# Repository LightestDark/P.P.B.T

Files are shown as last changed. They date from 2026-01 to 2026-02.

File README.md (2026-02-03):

# P.P.B.T

This project is a low-power smart keychain that combines E-paper display technology with NFC, designed to work with minimal energy and remain readable even when completely unpowered.

The system is split into two separate modules:

-E-Paper + NFC Keychain Board

Waveshare e paper display is used, following the websites recommended parts, using a crystal oscillator for graphics and a tiny flash memory for the images!
Used an NFC tag plugin for the coil for the NFC tag which calculates the impedance of the coil!

Added extra male pins for future endeavours if i want to add things to the board?

-Solar-Powered DC-DC Booster Board (external, detachable)

Follows a old schematic for an IKEA outdoor light, repurposed with smaller parts to make it cheaper, it uses a buckboost converter to get a steady flow from the solar panel to safely charge or power anything, in my case a strip of leds i will stick on the board case!

**This separation keeps the keychain compact, efficient, and flexible.**

**E PAPER + NFC SCHEMATIC/BOARD/MODEL:**







** SOLAR POWERED PSU **







The e-paper display shows text or graphics and keeps the image with zero power. Power is only needed when the display updates.
The NFC works passively, powered by the reader, allowing phones to scan the keychain even if the battery is empty.

To keep the main board simple and efficient, LED lighting is powered by a separate solar-powered DC-DC booster board. This board takes energy from a small solar panel and boosts it to drive LEDs around the keychain, without affecting the e-paper or NFC system.

CASE:

Pretty happy with the colour scheme and how it looks!





Main points of note:
PLA (probably)
Added tolerances for easy fitting since im hoping to use a friciton for the lid and the bottom
Added heat set insert holes
Added male header pin space for added functionality in the future
Added solar powered pcb on the underside, that will be wired to external solar panel and a led strip stuck onto the board
Added keychain hole onto the board (for coolness)

Underside:


Solar powered pcb on underside:



Under the hood:




Hopefully this is good enough to protect the board!

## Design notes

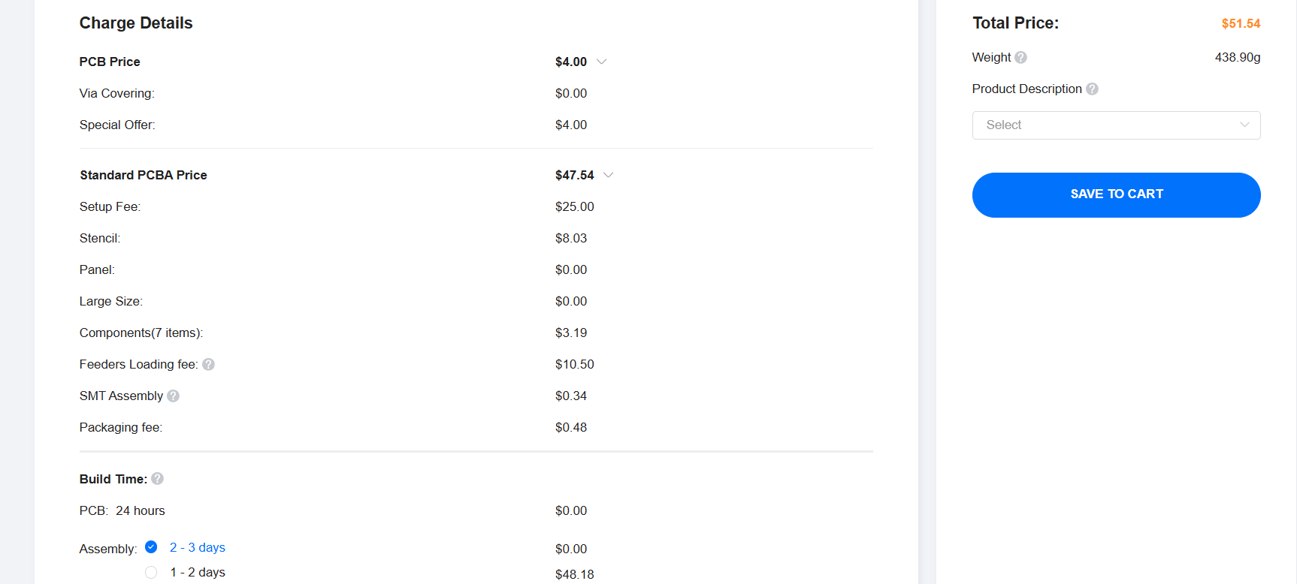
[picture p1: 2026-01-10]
Pictures/Jclpcb pt 2.png

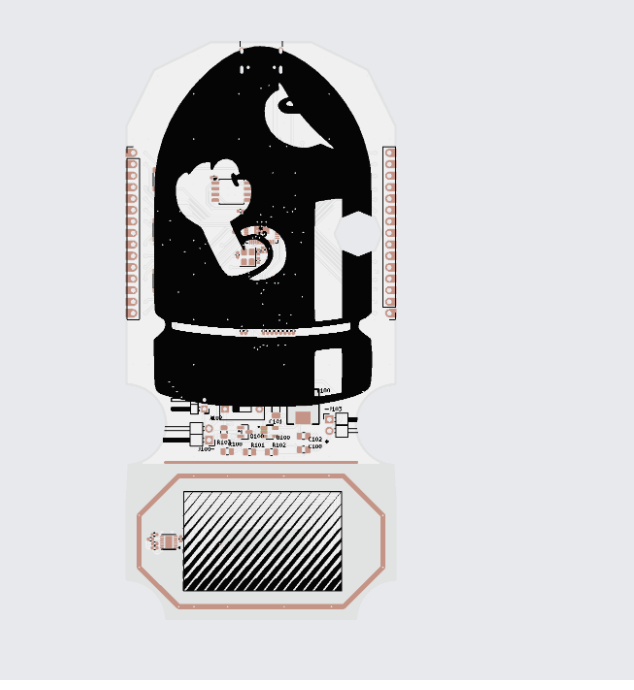
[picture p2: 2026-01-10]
Pictures/Screenshot 2026-01-10 211034.png

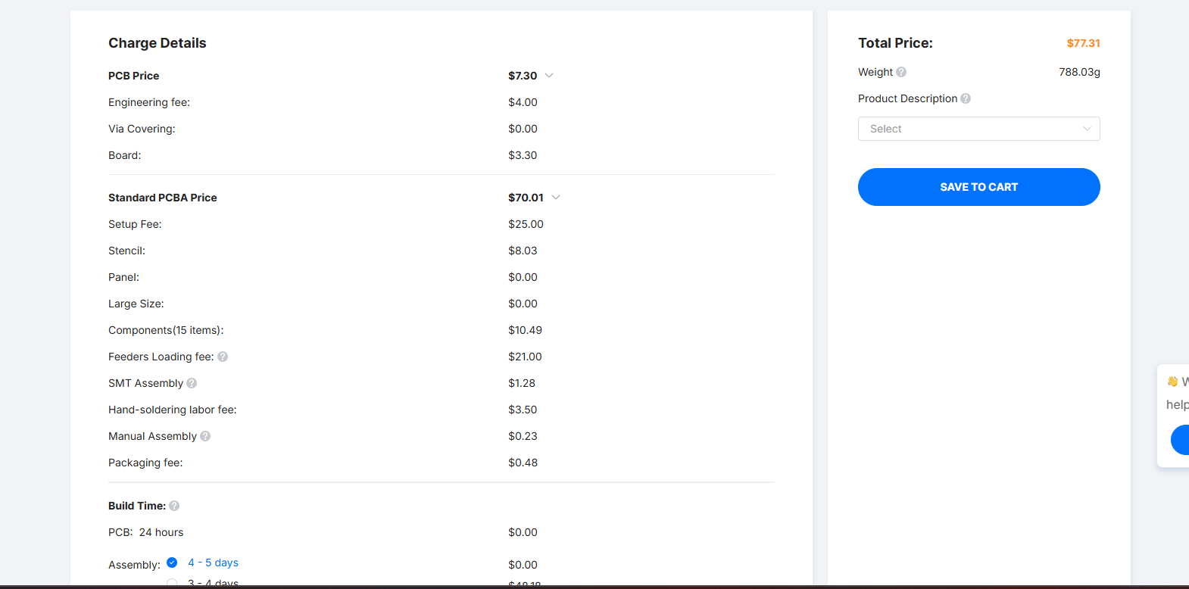
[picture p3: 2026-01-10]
Pictures/JCLPCB1.png

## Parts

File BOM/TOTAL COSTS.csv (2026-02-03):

Item No | Category | Item Name | Source | Unit Cost (USD) | Notes
1 | JLCPCB Assembly | E-Paper + NFC Board | JLCPCB | 94.58 | Full PCB fabrication + assembly
2 | JLCPCB Assembly | Solar Panel PSU Board | JLCPCB | 29.89 | Boost converter PCB fabrication + assembly
3 | External (Not JLCPCB) | 2.9 inch E-Paper Display | Waveshare | 15.00 | https://www.waveshare.com/2.9inch-e-paper-module-g.htm?sku=33215
4 | External (Not JLCPCB) | Solar Panel Module | Amazon | 5.00 | https://www.amazon.co.uk/dp/B0BKLP2B96
5 | Total | GRAND TOTAL (INC SHIPPING) |  | 154.85 | Sum of all costs

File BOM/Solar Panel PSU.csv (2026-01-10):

Comment | Designator | Footprint | LCSC / Source Part # | Manufacturer / MPN | Quantity | Unit Price (USD) | Total (USD)
DC-DC Boost Converter | U1 | SOT-23-5 | C20582 | AP3015AKTR-G1 | 1 | 0.23 | 0.23
Inductor 10uH | L1 | 0603 | C19702 | LQM15AN103B0D | 1 | 0.12 | 0.12
Schottky Diode | D1 | SMA | C8678 | SS14 | 1 | 0.06 | 0.06
Schottky Diode | D2 | SMA | C8678 | SS14 | 1 | 0.06 | 0.06
N-Channel MOSFET | Q1 | SOT-23 | C8545 | 2N7002 | 1 | 0.05 | 0.05
Resistor 1M | R1 | 0603 | C22936 | 0603WAF1004T5E | 1 | 0.001 | 0.001
Resistor 604k | R2 | 0603 | C25809 | 0603WAF6043T5E | 1 | 0.002 | 0.002
Resistor 100k | R3 | 0603 | C25803 | 0603WAF1003T5E | 1 | 0.001 | 0.001
Resistor 10Ω | R4 | 0603 | C22859 | 0603WAF100JT5E | 1 | 0.001 | 0.001
Capacitor 4.7uF 50V | C1 | 0805 | C29823 | CL21B475KBFNNNE | 1 | 0.03 | 0.03
Capacitor 22uF 10V | C2 | 1206 | C13585 | CL31A226KPHNNNE | 1 | 0.08 | 0.08
Capacitor 10uF 50V | C3 | 0805 | C15850 | CL21B106KPQNNNE | 1 | 0.05 | 0.05
2-Pin Header | J1 | Through-hole | C124378 | PinHeader 2P 2.54mm | 1 | 0.05 | 0.05
2-Pin Header | J2 | Through-hole | C124378 | PinHeader 2P 2.54mm | 1 | 0.05 | 0.05
2-Pin Header | J4 | Through-hole | C124378 | PinHeader 2P 2.54mm | 1 | 0.05 | 0.05
Slide Switch | SW1 | Through-hole | C318884 | Mini Slide Switch | 1 | 0.25 | 0.25
Solar Panel | SP1 | Wire leads | Elektor 11931 | Elektor 11931 | 1 | 6.50 | 6.50

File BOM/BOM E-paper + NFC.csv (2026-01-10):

JLCPCB BOM Tool - BOM Matching
BOM name：bom-JLCPCB Assembly Order.xlsx |  |  | Download Time：2026-01-05 06:33:50 |  |  |  | * Our matching results are updated in real-time, but stock and prices may change. If it's been over 24 hours, please re-match before placing your order.
PCB Assembled Qty：5 |  |  | Est. Total Price：15.1631
Your BOM |  |  |  |  | Matched Parts |  |  |  |  |  |  | Order Information
Top Designator | Bottom Designator | Comment | Footprint | JLCPCB Part # | Matches | Part # | Manufacturer | Footprint | Description | Category | Warning | JLCPCB Part # | Product link | Lib Type | Qty | Source | Total Price ($)
C1,C2 |  | 10uF | 0805 |  | Select by System | CL21A106KAYNNNE | Samsung Electro-Mechanics | 0805 | 10uF 25V X5R ±10% 0805 Multilayer Ceramic Capacitors MLCC - SMD/SMT ROHS | Multilayer Ceramic Capacitors MLCC - SMD/SMT |  | C15850 | https://jlcpcb.com/partdetail/16532-CL21A106KAYNNNE/C15850 | Basic | 10 | 10 JLCPCB | 0.098
C10,C12,C13,C16,C29,C4,C5,C6,C7,C8,C9 |  | 0.1uF | 0402 |  | Unconfirmed | CL05B104KO5NNNC | Samsung Electro-Mechanics | 0402 | 100nF 16V X7R ±10% 0402 Multilayer Ceramic Capacitors MLCC - SMD/SMT ROHS | Multilayer Ceramic Capacitors MLCC - SMD/SMT | 1.The comment (CL05B104KO5NNNC) of this part does not match the one (0.1uF) provided in your BOM. Please confirm; | C1525 | https://jlcpcb.com/partdetail/1877-CL05B104KO5NNNC/C1525 | Basic | 55 | 55 JLCPCB | 0.066
C11,C17,C18,C19,C20,C21,C22,C23,C24,C25,C26,C3 |  | 1uF | 0402 |  | Select by System | CL05A105KA5NQNC | Samsung Electro-Mechanics | 0402 | 1uF 25V X5R ±10% 0402 Multilayer Ceramic Capacitors MLCC - SMD/SMT ROHS | Multilayer Ceramic Capacitors MLCC - SMD/SMT |  | C52923 | https://jlcpcb.com/partdetail/53938-CL05A105KA5NQNC/C52923 | Basic | 60 | 60 JLCPCB | 0.174
C14,C15,C30 |  | 33pF | 0402 |  | Select by System | 0402CG330J500NT | FH (Guangdong Fenghua Advanced Tech) | 0402 | 33pF 50V C0G ±5% 0402 Multilayer Ceramic Capacitors MLCC - SMD/SMT ROHS | Multilayer Ceramic Capacitors MLCC - SMD/SMT |  | C1562 | https://jlcpcb.com/partdetail/1914-0402CG330J500NT/C1562 | Basic | 15 | 15 JLCPCB | 0.015
C27,C28 |  | 4.7uF | 0603 |  | Select by System | CL10A475KO8NNNC | Samsung Electro-Mechanics | 0603 | 16V 4.7uF X5R ±10% 0603 Multilayer Ceramic Capacitors MLCC - SMD/SMT ROHS | Multilayer Ceramic Capacitors MLCC - SMD/SMT |  | C19666 | https://jlcpcb.com/partdetail/20375-CL10A475KO8NNNC/C19666 | Basic | 10 | 10 JLCPCB | 0.092
D1 |  | KT-0805G | 0805 |  | Select by System | KT-0805G | Hubei KENTO Elec | 0805 | -40℃~+85℃ 100mW 120° 2.6V~3.1V 430mcd 513nm~528nm 525nm 5mA Emerald Green 0805 LED Indication - Discrete ROHS | LED Indication - Discrete |  | C2297 | https://jlcpcb.com/partdetail/Hubei_KENTOElec-KT0805G/C2297 | Basic | 5 | 5 JLCPCB | 0.054
D2,D3,D4 |  | MBR0530 | D_SOD-123 |  | Select by System | MBR0530 | TWGMC | SOD-123 | 130uA 30V 5.5A 500mA 500mV@500mA Independent SOD-123 Schottky Diodes ROHS | Schottky Diodes |  | C5204746 | https://jlcpcb.com/partdetail/TWGMC-MBR0530/C5204746 | Extended | 23 | 23 JLCPCB | 0.4278
J1 |  | USB_C_Receptacle_USB2.0_16P | USB_C_Receptacle_HRO_TYPE-C-31-M-12 |  | Select by Customer | TYPE-C-31-M-12 | Korean Hroparts Elec | SMD | 1 16P 5A Female Type-C SMD USB Connectors ROHS | USB Connectors |  | C165948 | https://jlcpcb.com/partdetail/Korean_HropartsElec-TYPE_C_31_M12/C165948 | Extended | 5 | 5 JLCPCB | 0.847
L2 |  | 68uH | L_Changjiang_FNR6028S |  | Select by Customer | FNR6028S680MT | cjiang (Changjiang Microelectronics Tech) | SMD,6x6mm | 468mΩ 68uH 950mA 950mA Magnetic Shielded Inductor ±20% SMD,6x6mm Power Inductors ROHS | Power Inductors |  | C168045 | https://jlcpcb.com/partdetail/179428-FNR6028S680MT/C168045 | Extended | 6 | 6 JLCPCB | 0.3978
Q2 |  | IRLML2060 | SOT-23 |  | Unconfirmed | IRLML2060TRPBF | TECH PUBLIC | SOT-23 | 105mΩ@10V 19.5pF 247pF 2V 34pF 350mW 3A 60V 6nC@4.5V SOT-23 MOSFETs ROHS | MOSFETs | 1.The comment (IRLML2060TRPBF) of this part does not match the one (IRLML2060) provided in your BOM. Please confirm; | C5122027 | https://jlcpcb.com/partdetail/TECHPUBLIC-IRLML2060TRPBF/C5122027 | Extended | 9 | 9 JLCPCB | 0.5607
R1,R2 |  | 5.1K | 0402 |  | Unconfirmed | 0402WGF5101TCE | UNI-ROYAL(Uniroyal Elec) | 0402 | -55℃~+155℃ 5.1kΩ 50V 62.5mW Thick Film Resistor ±1% ±100ppm/℃ 0402 Chip Resistor - Surface Mount ROHS | Chip Resistor - Surface Mount | 1.The comment (0402WGF5101TCE) of this part does not match the one (5.1K) provided in your BOM. Please confirm; | C25905 | https://jlcpcb.com/partdetail/26648-0402WGF5101TCE/C25905 | Basic | 10 | 10 JLCPCB | 0.005
R3,R4 |  | 22 | 0402 |  | Unconfirmed | 0402WGF220JTCE | UNI-ROYAL(Uniroyal Elec) | 0402 | -55℃~+155℃ 22Ω 50V 62.5mW Thick Film Resistor ±1% ±100ppm/℃ 0402 Chip Resistor - Surface Mount ROHS | Chip Resistor - Surface Mount | 1.The comment (0402WGF220JTCE) of this part does not match the one (22) provided in your BOM. Please confirm; | C25092 | https://jlcpcb.com/partdetail/25835-0402WGF220JTCE/C25092 | Basic | 10 | 10 JLCPCB | 0.006
R6,R9 |  | 1K | 0402 |  | Unconfirmed | 0402WGF1001TCE | UNI-ROYAL(Uniroyal Elec) | 0402 | -55℃~+155℃ 1kΩ 50V 62.5mW Thick Film Resistor ±1% ±100ppm/℃ 0402 Chip Resistor - Surface Mount ROHS | Chip Resistor - Surface Mount | 1.The comment (0402WGF1001TCE) of this part does not match the one (1K) provided in your BOM. Please confirm; | C11702 | https://jlcpcb.com/partdetail/12256-0402WGF1001TCE/C11702 | Basic | 10 | 10 JLCPCB | 0.006
R7 |  | 220 | 0402 |  | Unconfirmed | 0402WGF2200TCE | UNI-ROYAL(Uniroyal Elec) | 0402 | -55℃~+155℃ 220Ω 50V 62.5mW Thick Film Resistor ±1% ±100ppm/℃ 0402 Chip Resistor - Surface Mount ROHS | Chip Resistor - Surface Mount | 1.The comment (0402WGF2200TCE) of this part does not match the one (220) provided in your BOM. Please confirm; | C25091 | https://jlcpcb.com/partdetail/25834-0402WGF2200TCE/C25091 | Basic | 5 | 5 JLCPCB | 0.003
R10,R11,R13,R14,R5,R8 |  | 10K | 0402 |  | Unconfirmed | 0402WGF1002TCE | UNI-ROYAL(Uniroyal Elec) | 0402 | -55℃~+155℃ 10kΩ 50V 62.5mW Thick Film Resistor ±1% ±100ppm/℃ 0402 Chip Resistor - Surface Mount ROHS | Chip Resistor - Surface Mount | 1.The comment (0402WGF1002TCE) of this part does not match the one (10K) provided in your BOM. Please confirm; | C25744 | https://jlcpcb.com/partdetail/26487-0402WGF1002TCE/C25744 | Basic | 30 | 30 JLCPCB | 0.015
R12 |  | 0.47 | 0402 |  | Unconfirmed | 0402WGF470LTCE | UNI-ROYAL(Uniroyal Elec) | 0402 | -55℃~+155℃ 470mΩ 50V 62.5mW Thick Film Resistor ±1% ±800ppm/℃ 0402 Chip Resistor - Surface Mount ROHS | Chip Resistor - Surface Mount | 1.The comment (0402WGF470LTCE) of this part does not match the one (0.47) provided in your BOM. Please confirm; | C423162 | https://jlcpcb.com/partdetail/416112-0402WGF470LTCE/C423162 | Extended | 20 | 20 JLCPCB | 0.078
SW1,SW2,SW3 |  | TSA016A2526B | SW_Push_SPST_TSA016 |  | Select by System | TSA016A2526B | BZCN | SMD,4.2x3.4mm | 12V 2.5mm 2.6N 3.35mm 4.2mm 50mA Oval Button Surface Mount,Vertical White SMD,4.2x3.4mm Tactile Switches ROHS | Tactile Switches |  | C2888429 | https://jlcpcb.com/partdetail/BZCN-TSA016A2526B/C2888429 | Extended | 20 | 20 JLCPCB | 0.418
U1 |  | RP2040 | QFN-56-1EP_7x7mm_P0.4mm_EP3.2x3.2mm |  | Select by Customer | RP2040 | Raspberry Pi | LQFN-56(7x7) | 12bit 133MHz 30 LQFN-56(7x7) Microcontrollers (MCU/MPU/SOC) ROHS | Microcontrollers (MCU/MPU/SOC) |  | C2040 | https://jlcpcb.com/partdetail/RaspberryPi-RP2040/C2040 | Extended | 5 | 5 JLCPCB | 4.5825
U2 |  | USBLC6-2SC6 | SOT-23-6 |  | Select by System | USBLC6-2SC6 | TECH PUBLIC | SOT-23-6 | -55℃~+125℃ 0.35pF 12V 150W 2 5V 6A 6V 80nA ESD IEC 61000-4-2 Unidirectional SOT-23-6 ESD and Surge Protection (TVS/ESD) ROHS | ESD And Surge Protection (TVS/ESD) |  | C2827654 | https://jlcpcb.com/partdetail/TECHPUBLIC-USBLC62SC6/C2827654 | Extended | 9 | 9 JLCPCB | 0.3348
U3 |  | NCP1117ST33T3G | SOT-223-3_TabPin2 |  | Select by System | NCP1117ST33T3G | onsemi | SOT-223 | 0.003%Vout 0℃~+125℃@(Ta) 1 1.2V@(800mA) 1A 20V 3.3V 62dB@(120Hz) 6mA Fixed Over Current Protection Positive SOT-223 Voltage Regulators - Linear, Low Drop Out (LDO) Regulators ROHS | Voltage Regulators - Linear, Low Drop Out (LDO) Regulators |  | C26537 | https://jlcpcb.com/partdetail/onsemi-NCP1117ST33T3G/C26537 | Extended | 5 | 5 JLCPCB | 1.119
U4 |  | W25Q32JVSS | SOIC-8_5.3x5.3mm_P1.27mm |  | Unconfirmed | W25Q32JVSSIQ | Winbond Elec | SOIC-8-208mil | -40℃~+85℃ 100,000 Cycles 133MHz 1uA 2.7V~3.6V 20 Years 32Mbit 3ms SPI SOIC-8-208mil NOR FLASH ROHS | NOR FLASH | 1.The comment (W25Q32JVSSIQ) of this part does not match the one (W25Q32JVSS) provided in your BOM. Please confirm; | C179173 | https://jlcpcb.com/partdetail/WinbondElec-W25Q32JVSSIQ/C179173 | Extended | 5 | 5 JLCPCB | 3.2475
U5 |  | Conn | LCSC_1x24-1MP_P0.5mm_Horizontal |  | Select by System | AFC07-S24FCA-00 | JUSHUO | SMD,P=0.5mm,卧贴 | 0.3mm 0.5mm 24P 2mm Bottom Contact Copper Alloy Slide Lock Surface Mount, Right Angle Tin SMD,P=0.5mm,Surface Mount，Right Angle FFC, FPC (Flat Flexible) Connector Assemblies ROHS | FFC, FPC (Flat Flexible) Connector Assemblies |  | C262567 | https://jlcpcb.com/partdetail/JUSHUO-AFC07_S24FCA00/C262567 | Extended | 5 | 5 JLCPCB | 0.5985
U6 |  | ST25DV04K-JFR6D3 | ST_UFDFPN-12-1EP_3x3mm_P0.5mm_EP1.4x2.55mm |  | Select by System | ST25DV04K-JFR6D3 | STMicroelectronics | UDFN-12-EP(3x3) | 1.8V~5.5V 53Kbit/s I2C ISO 15693,NFC UDFN-12-EP(3x3) RFID ICs ROHS | RFID ICs |  | C2654815 | https://jlcpcb.com/partdetail/STMicroelectronics-ST25DV04KJFR6D3/C2654815 | Extended | 5 | 5 JLCPCB | 1.695
Y1 |  | 12MHz | Crystal_SMD_3225-4Pin_3.2x2.5mm |  | Select by Customer | X322512MSB4SI | YXC Crystal Oscillators | SMD3225-4P | -40℃~+85℃ 12MHz 20pF Crystal Oscillator ±10ppm ±20ppm SMD3225-4P Crystals ROHS | Crystals |  | C9002 | https://jlcpcb.com/partdetail/YXC_CrystalOscillators-X322512MSB4SI/C9002 | Basic | 5 | 5 JLCPCB | 0.3225
J2,J3 |  | Conn_01x15 | PinHeader_PAD_1x15_P2.54mm_Vertical |  | No matches | No Part Selected
L1 |  | NFCAntenna | 25x35mm-NFC |  | No matches | No Part Selected

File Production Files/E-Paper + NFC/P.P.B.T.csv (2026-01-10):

Reference | Qty | Value | DNP | Exclude from BOM | Exclude from Board | Footprint | Datasheet
C1,C2 | 2 | 10uF |  |  |  | Capacitor_SMD:C_0805_2012Metric | ~
C3,C11,C17,C18,C19,C20,C21,C22,C23,C24,C25,C26 | 12 | 1uF |  |  |  | Capacitor_SMD:C_0402_1005Metric | ~
C4,C5,C6,C7,C8,C9,C10,C12,C13,C16,C29 | 11 | 0.1uF |  |  |  | Capacitor_SMD:C_0402_1005Metric | ~
C14,C15,C30 | 3 | 33pF |  |  |  | Capacitor_SMD:C_0402_1005Metric | ~
C27,C28 | 2 | 4.7uF |  |  |  | Capacitor_SMD:C_0603_1608Metric | ~
C101 | 1 | 4.7 μF 50 V X7R |  |  |  | Capacitor_SMD:C_0805_2012Metric | ~
C102 | 1 | 10 pF 50 V X7R |  |  |  | Capacitor_SMD:C_0805_2012Metric | ~
C103 | 1 | 22 μF 10 V X7R |  |  |  | Capacitor_SMD:C_1206_3216Metric | ~
D1 | 1 | KT-0805G |  |  |  | LED_SMD:LED_0805_2012Metric | ~
D2,D3,D4 | 3 | MBR0530 |  |  |  | Diode_SMD:D_SOD-123 | http://www.mccsemi.com/up_pdf/MBR0520~MBR0580(SOD123).pdf
D101,D102 | 2 | SS14 |  |  |  | SS14:DIOM4325X250N
J1 | 1 | USB_C_Receptacle_USB2.0_16P |  |  |  | Connector_USB:USB_C_Receptacle_HRO_TYPE-C-31-M-12 | https://www.usb.org/sites/default/files/documents/usb_type-c.zip
J2,J3 | 2 | Conn_01x15 |  |  |  | kai's library:PinHeader_PAD_1x15_P2.54mm_Vertical | ~
J101 | 1 | Conn_01x02_Pin |  |  |  | Connector_PinHeader_2.00mm:PinHeader_1x02_P2.00mm_Horizontal | ~
J102,J103,J104 | 3 | Conn_01x02_Pin |  |  |  | Connector_PinHeader_2.54mm:PinHeader_1x02_P2.54mm_Vertical | ~
L1 | 1 | NFC Antenna |  |  |  | nfc:25x35mm-NFC | ~
L2 | 1 | 68uH |  |  |  | Inductor_SMD:L_Changjiang_FNR6028S | ~
L101 | 1 | ASPI-0630LR-100M-T15 |  |  |  | footprints_coil:IND_ASPI-0630LR_ABR | ASPI-0630LR-100M-T15
Q2 | 1 | IRLML2060 |  |  |  | Package_TO_SOT_SMD:SOT-23 | https://www.infineon.com/dgdl/irlml2060pbf.pdf?fileId=5546d462533600a401535664b7fb25ee
Q101 | 1 | 2N7002 |  |  |  | Package_TO_SOT_SMD:SOT-23 | https://www.onsemi.com/pub/Collateral/NDS7002A-D.PDF
R1,R2 | 2 | 5.1K |  |  |  | Resistor_SMD:R_0402_1005Metric | ~
R3,R4 | 2 | 22 |  |  |  | Resistor_SMD:R_0402_1005Metric | ~
R5,R8,R10,R11,R13,R14 | 6 | 10K |  |  |  | Resistor_SMD:R_0402_1005Metric | ~
R6,R9 | 2 | 1K |  |  |  | Resistor_SMD:R_0402_1005Metric | ~
R7 | 1 | 220 |  |  |  | Resistor_SMD:R_0402_1005Metric | ~
R12 | 1 | 0.47 |  |  |  | Resistor_SMD:R_0402_1005Metric | ~
R101,R103 | 2 | 1 ΜΩ |  |  |  | Resistor_SMD:R_0805_2012Metric | ~
R102 | 1 | 10 kΩ |  |  |  | Resistor_SMD:R_0805_2012Metric | ~
R104 | 1 | 604 kΩ 1% |  |  |  | Resistor_SMD:R_0805_2012Metric | ~
SW1,SW2,SW3 | 3 | TSA016A2526B |  |  |  | kai's library:SW_Push_SPST_TSA016 | ~
U1 | 1 | RP2040 |  |  |  | Package_DFN_QFN:QFN-56-1EP_7x7mm_P0.4mm_EP3.2x3.2mm | https://datasheets.raspberrypi.com/rp2040/rp2040-datasheet.pdf
U2 | 1 | USBLC6-2SC6 |  |  |  | Package_TO_SOT_SMD:SOT-23-6 | https://www.st.com/resource/en/datasheet/usblc6-2.pdf
U3 | 1 | NCP1117ST33T3G |  |  |  | Package_TO_SOT_SMD:SOT-223-3_TabPin2 | http://www.onsemi.com/pub_link/Collateral/NCP1117-D.PDF
U4 | 1 | W25Q32JVSS |  |  |  | Package_SO:SOIC-8_5.3x5.3mm_P1.27mm | http://www.winbond.com/resource-files/w25q32jv%20revg%2003272018%20plus.pdf
U5 | 1 | Conn |  |  |  | kai's library:LCSC_1x24-1MP_P0.5mm_Horizontal
U6 | 1 | ST25DV04K-JFR6D3 |  |  |  | Package_DFN_QFN:ST_UFDFPN-12-1EP_3x3mm_P0.5mm_EP1.4x2.55mm | https://www.st.com/resource/en/datasheet/st25dv04k.pdf
U101 | 1 | AP3015AKTR-G1 |  |  |  | AP3015AKTR-G1:SOT95P280X145-5N
Y1 | 1 | 12MHz |  |  |  | Crystal:Crystal_SMD_3225-4Pin_3.2x2.5mm | ~

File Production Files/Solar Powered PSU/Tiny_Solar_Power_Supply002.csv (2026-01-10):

Reference | Qty | Value | DNP | Exclude from BOM | Exclude from Board | Footprint | Short Description
C1 | 1 | 4.7uF, 50V, X7R (0805) |  |  |  | Capacitor_SMD:C_0805_2012Metric
C2 | 1 | 22uF, 10V, X7R (1206) |  |  |  | Capacitor_SMD:C_1206_3216Metric
C3 | 1 | 10pF, 50V, X7R (0805) |  |  |  | Capacitor_SMD:C_0805_2012Metric
D1,D2 | 2 | SS14 |  |  |  | Diode_SMD:D_SMA
J1,J2,J3 | 3 | Conn_01x02_Pin |  |  |  | Connector_PinHeader_2.54mm:PinHeader_1x02_P2.54mm_Vertical | BAT,ON/OFF,OUT
J4 | 1 | Conn_01x02_Pin |  |  |  | Connector_PinHeader_2.54mm:PinHeader_1x02_P2.54mm_Horizontal | SOLAR
L1 | 1 | LQW15AN1N3C80D |  |  |  | IND_LQW15_MUR
Q1 | 1 | 2N7002 |  |  |  | digikey-footprints:SOT-23-3
R1,R4 | 2 | 1MOhm |  |  |  | Resistor_SMD:R_0805_2012Metric
R2 | 1 | 604 kOhm |  |  |  | Resistor_SMD:R_0805_2012Metric
R3 | 1 | 10kOhm |  |  |  | Resistor_SMD:R_0805_2012Metric
U1 | 1 | AP3015AKTR-G1 |  |  |  | footprints:SOT23-5_1P55X2P9_DIO

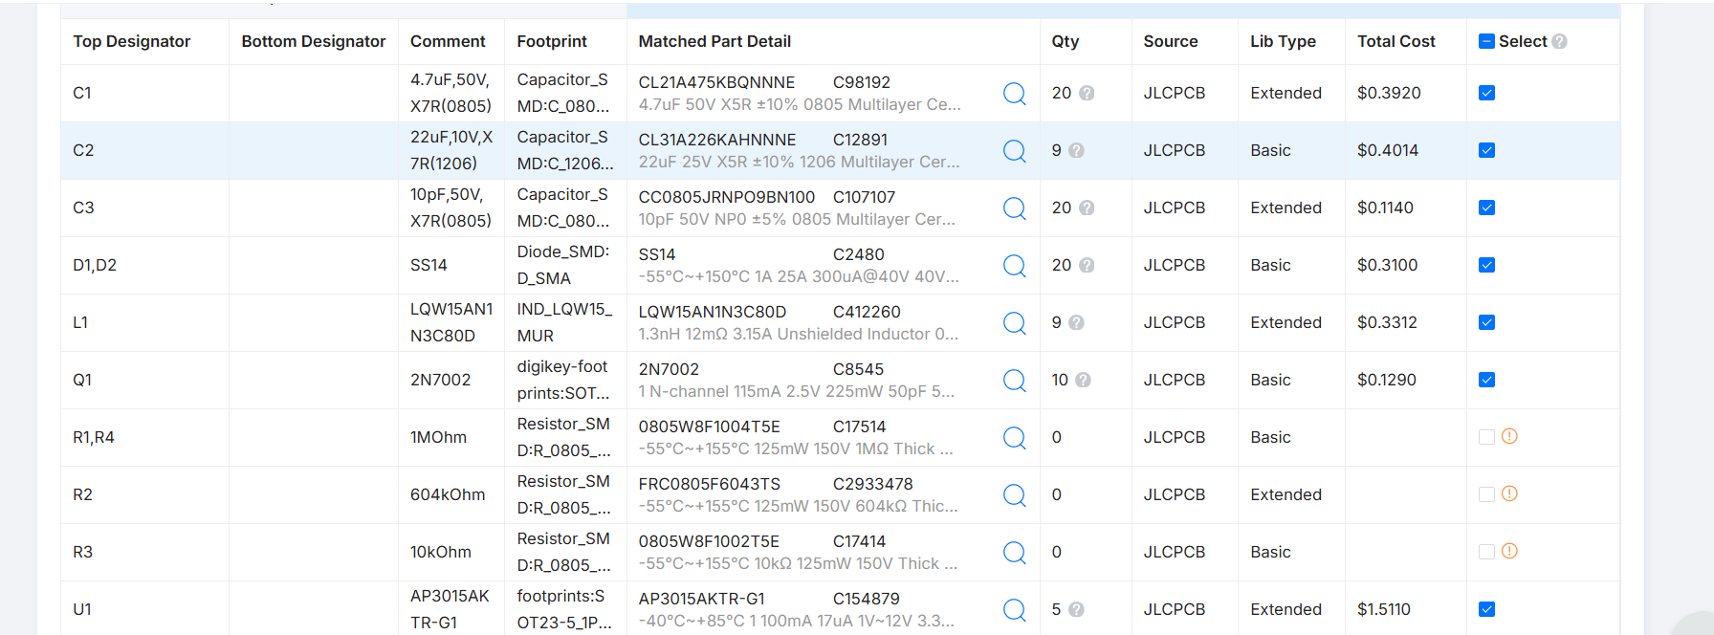
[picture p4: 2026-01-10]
Pictures/Bom pic solar.png

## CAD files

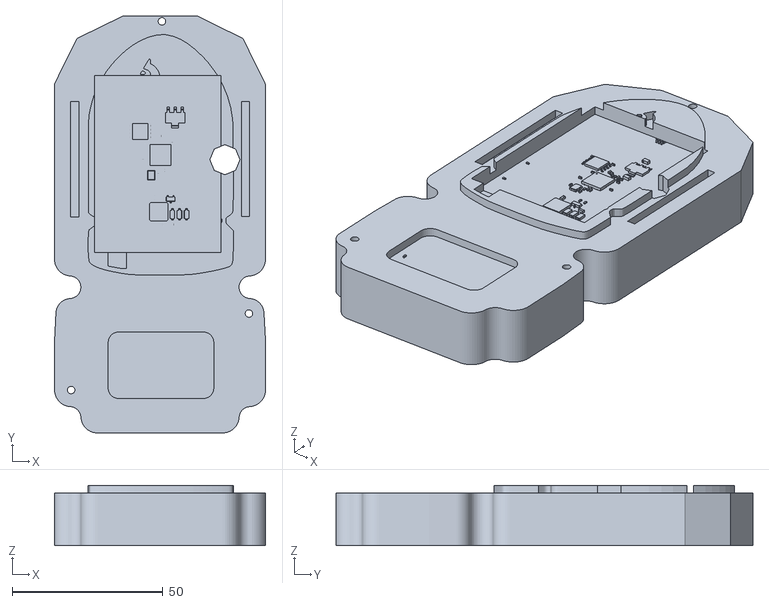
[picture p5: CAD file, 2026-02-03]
CAD/P.P.B.T CASING.stl
70.0 x 138.4 x 20.0

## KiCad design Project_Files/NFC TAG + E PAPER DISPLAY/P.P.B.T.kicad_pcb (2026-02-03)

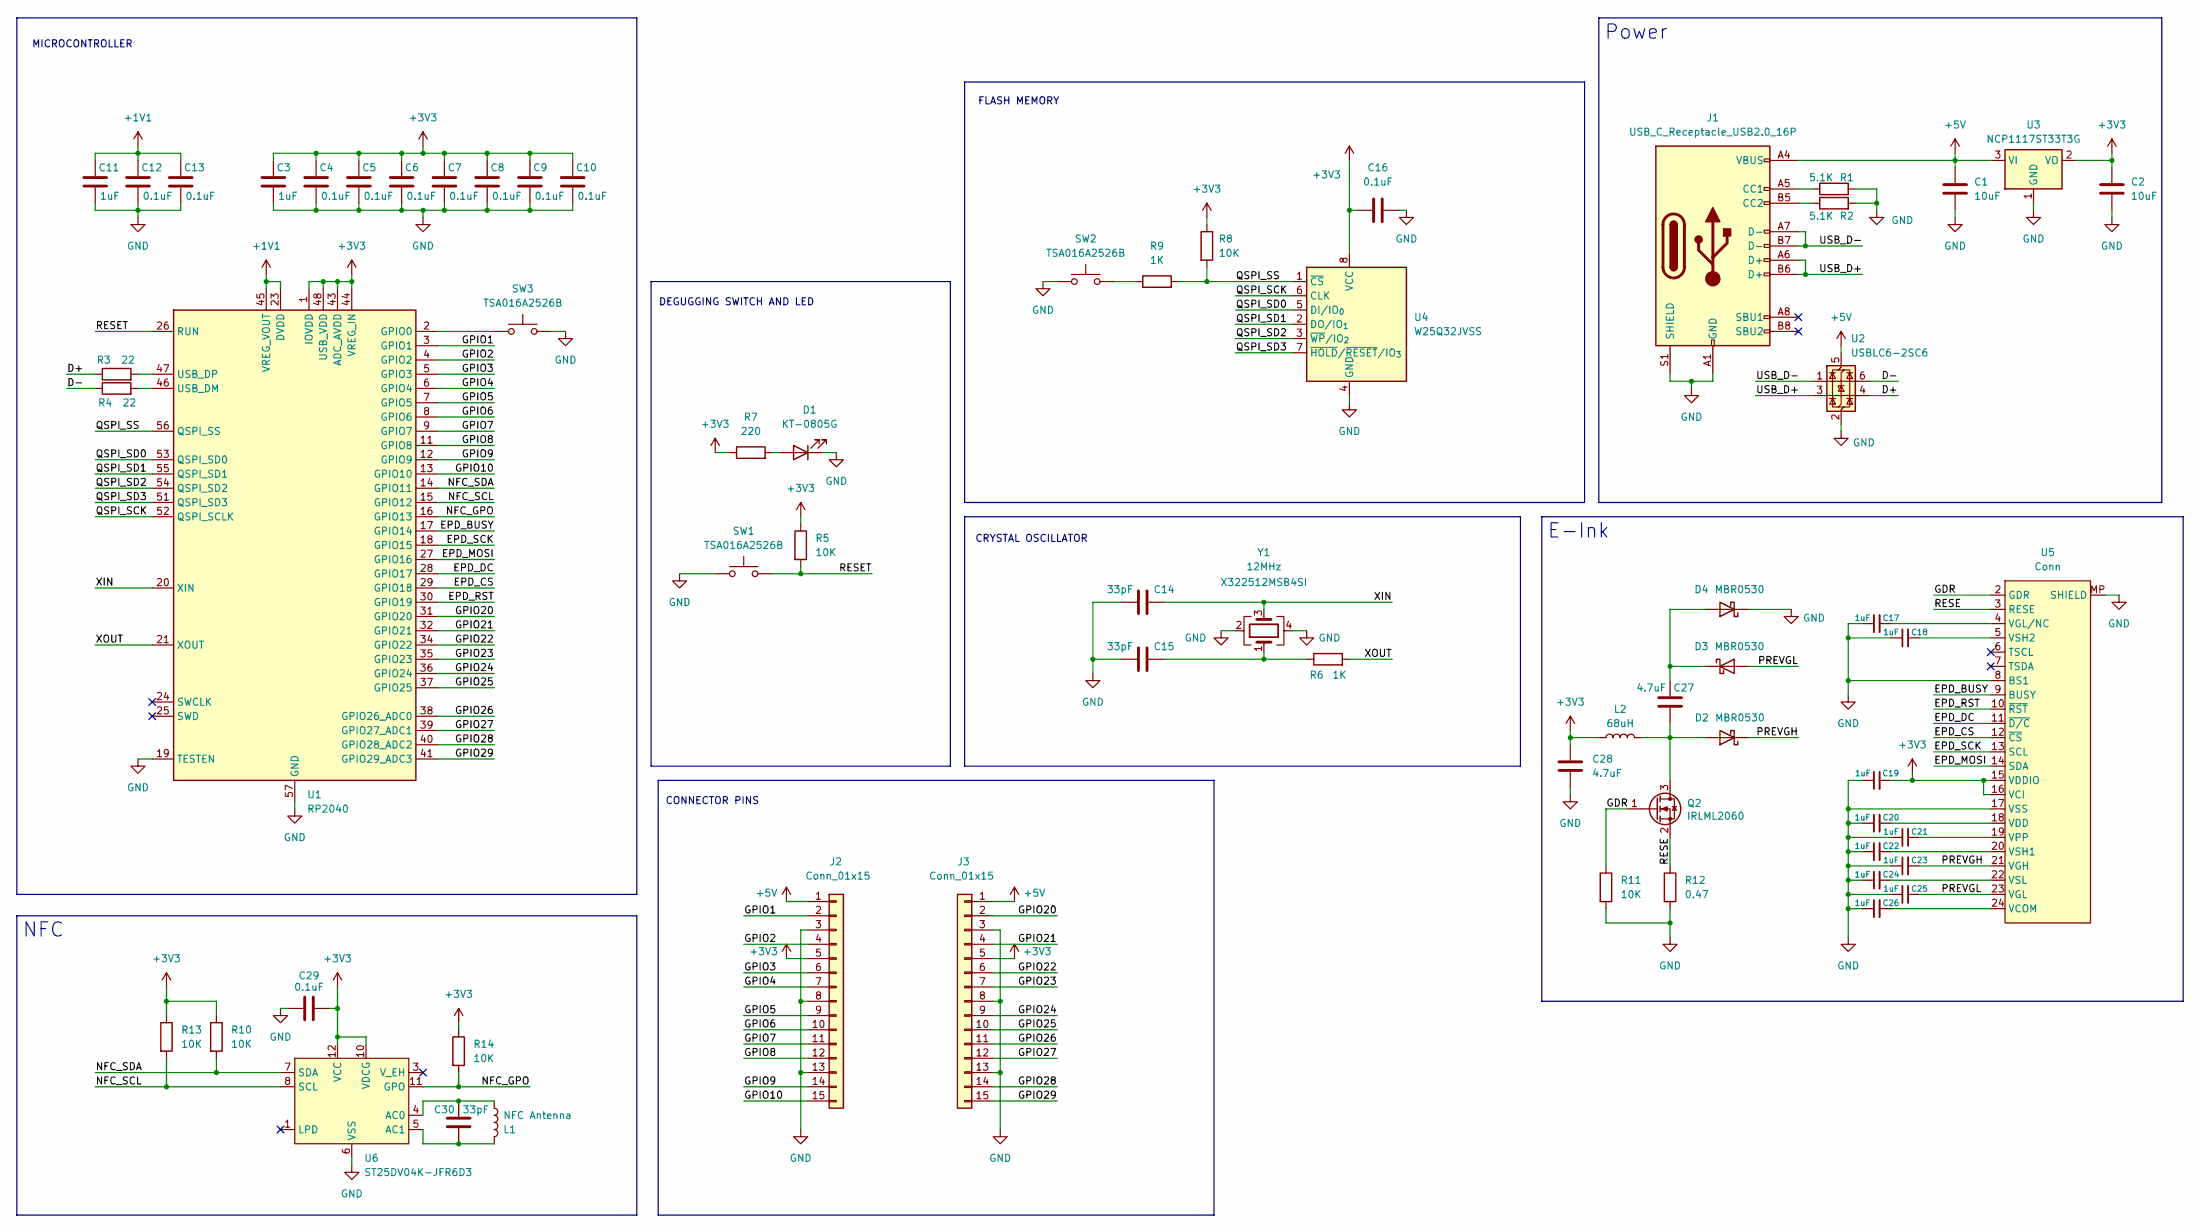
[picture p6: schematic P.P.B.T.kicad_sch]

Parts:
C1, C2: 10uF; C_0805_2012Metric
C3, C11, C17, C18, C19, C20, C21, C22, C23, C24, C25, C26: 1uF; C_0402_1005Metric
C4, C5, C6, C7, C8, C9, C10, C12, C13, C16, C29: 0.1uF; C_0402_1005Metric
C14, C15, C30: 33pF; C_0402_1005Metric
C27, C28: 4.7uF; C_0603_1608Metric
D1: KT-0805G; LED_0805_2012Metric
D2, D3, D4: MBR0530; D_SOD-123
J1: USB_C_Receptacle_USB2.0_16P; USB_C_Receptacle_HRO_TYPE-C-31-M-12
J2, J3: Conn_01x15; PinHeader_PAD_1x15_P2.54mm_Vertical
L1: NFC Antenna; 25x35mm-NFC
L2: 68uH; L_Changjiang_FNR6028S; MPN FNR6028S680MT
Q2: IRLML2060; SOT-23
R1, R2: 5.1K; R_0402_1005Metric
R3, R4: 22; R_0402_1005Metric
R5, R8, R10, R11, R13, R14: 10K; R_0402_1005Metric
R6, R9: 1K; R_0402_1005Metric
R7: 220; R_0402_1005Metric
R12: 0.47; R_0402_1005Metric
SW1, SW2, SW3: TSA016A2526B; SW_Push_SPST_TSA016
U1: RP2040; QFN-56-1EP_7x7mm_P0.4mm_EP3.2x3.2mm
U2: USBLC6-2SC6; SOT-23-6
U3: NCP1117ST33T3G; SOT-223-3_TabPin2
U4: W25Q32JVSS; SOIC-8_5.3x5.3mm_P1.27mm
U5: Conn; LCSC_1x24-1MP_P0.5mm_Horizontal; LCSC Part # C262567
U6: ST25DV04K-JFR6D3; ST_UFDFPN-12-1EP_3x3mm_P0.5mm_EP1.4x2.55mm
Y1: 12MHz; Crystal_SMD_3225-4Pin_3.2x2.5mm; MPN X322512MSB4SI

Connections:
+1V1: C11.1, C12.1, C13.1, U1.23 (DVDD), U1.45 (VREG_VOUT), U1.50 (DVDD)
+3V3: C2.1, C3.1, C4.1, C5.1, C6.1, C7.1, C8.1, C9.1, C10.1, C16.1, C19.2, C28.2, C29.2, J2.5, J3.5, L2.1, R5.1, R7.1, R8.1, R10.1, R13.1, R14.1, U1.1 (IOVDD), U1.10 (IOVDD), U1.22 (IOVDD), U1.33 (IOVDD), U1.42 (IOVDD), U1.43 (ADC_AVDD), U1.44 (VREG_IN), U1.48 (USB_VDD), U1.49 (IOVDD), U3.2 (VO), U4.8 (VCC), U5.15 (VDDIO), U5.16 (VCI), U6.10 (VDCG), U6.12 (VCC)
+5V: C1.1, J1.A4 (VBUS), J1.A9 (VBUS), J1.B4 (VBUS), J1.B9 (VBUS), J2.1, J3.1, U2.5 (VBUS), U3.3 (VI)
/D+: R3.1, U2.4 (I/O2)
/D-: R4.1, U2.6 (I/O1)
/EPD_BUSY: U1.17 (GPIO14), U5.9 (BUSY)
/EPD_CS: U1.29 (GPIO18), U5.12 (~CS)
/EPD_DC: U1.28 (GPIO17), U5.11 (~D/C)
/EPD_MOSI: U1.27 (GPIO16), U5.14 (SDA)
/EPD_RST: U1.30 (GPIO19), U5.10 (~RST)
/EPD_SCK: U1.18 (GPIO15), U5.13 (SCL)
/GDR: Q2.1 (G), R11.1, U5.2 (GDR)
/GPIO1: J2.2, U1.3 (GPIO1)
/GPIO2: J2.4, U1.4 (GPIO2)
/GPIO3: J2.6, U1.5 (GPIO3)
/GPIO4: J2.7, U1.6 (GPIO4)
/GPIO5: J2.9, U1.7 (GPIO5)
/GPIO6: J2.10, U1.8 (GPIO6)
/GPIO7: J2.11, U1.9 (GPIO7)
/GPIO8: J2.12, U1.11 (GPIO8)
/GPIO9: J2.14, U1.12 (GPIO9)
/GPIO10: J2.15, U1.13 (GPIO10)
/GPIO20: J3.2, U1.31 (GPIO20)
/GPIO21: J3.4, U1.32 (GPIO21)
/GPIO22: J3.6, U1.34 (GPIO22)
/GPIO23: J3.7, U1.35 (GPIO23)
/GPIO24: J3.9, U1.36 (GPIO24)
/GPIO25: J3.10, U1.37 (GPIO25)
/GPIO26: J3.11, U1.38 (GPIO26_ADC0)
/GPIO27: J3.12, U1.39 (GPIO27_ADC1)
/GPIO28: J3.14, U1.40 (GPIO28_ADC2)
/GPIO29: J3.15, U1.41 (GPIO29_ADC3)
/NFC_GPO: R14.2, U1.16 (GPIO13), U6.11 (GPO)
/NFC_SCL: R13.2, U1.15 (GPIO12), U6.8 (SCL)
/NFC_SDA: R10.2, U1.14 (GPIO11), U6.7 (SDA)
/PREVGH: C23.2, D2.1 (K), U5.21 (VGH)
/PREVGL: C25.2, D3.2 (A), U5.23 (VGL)
/QSPI_SCK: U1.52 (QSPI_SCLK), U4.6 (CLK)
/QSPI_SD0: U1.53 (QSPI_SD0), U4.5 (DI/IO_{0})
/QSPI_SD1: U1.55 (QSPI_SD1), U4.2 (DO/IO_{1})
/QSPI_SD2: U1.54 (QSPI_SD2), U4.3 (~WP/IO_{2})
/QSPI_SD3: U1.51 (QSPI_SD3), U4.7 (~HOLD/~RESET/IO_{3})
/QSPI_SS: R8.2, R9.2, U1.56 (QSPI_SS), U4.1 (~CS)
/RESE: Q2.2 (S), R12.1, U5.3 (RESE)
/RESET: R5.2, SW1.2, U1.26 (RUN)
/USB_D+: J1.A6 (D+), J1.B6 (D+), U2.3 (I/O2)
/USB_D-: J1.A7 (D-), J1.B7 (D-), U2.1 (I/O1)
/XIN: C14.2, U1.20 (XIN), Y1.3
/XOUT: R6.2, U1.21 (XOUT)
GND: C1.2, C2.2, C3.2, C4.2, C5.2, C6.2, C7.2, C8.2, C9.2, C10.2, C11.2, C12.2, C13.2, C14.1, C15.1, C16.2, C17.1, C18.1, C19.1, C20.1, C21.1, C22.1, C23.1, C24.1, C25.1, C26.1, C28.1, C29.1, D1.1 (K), D4.1 (K), J1.A1 (GND), J1.A12 (GND), J1.B1 (GND), J1.B12 (GND), J1.S1 (SHIELD), J2.3, J2.8, J2.13, J3.3, J3.8, J3.13, R1.2, R2.2, R11.2, R12.2, SW1.1, SW2.1, SW3.2, U1.19 (TESTEN), U1.57 (GND), U2.2 (GND), U3.1 (GND), U4.4 (GND), U5.8 (BS1), U5.17 (VSS), U5.MP (SHIELD), U6.6 (VSS), Y1.2, Y1.4
unnamed: C15.2, R6.1, Y1.1
unnamed: D1.2 (A), R7.2
unnamed: C27.2, D2.2 (A), L2.2, Q2.3 (D)
unnamed: C27.1, D3.1 (K), D4.2 (A)
unnamed: J1.A5 (CC1), R1.1
unnamed: J1.B5 (CC2), R2.1
unnamed: R9.1, SW2.2
unnamed: SW3.1, U1.2 (GPIO0)
unnamed: R4.2, U1.46 (USB_DM)
unnamed: R3.2, U1.47 (USB_DP)
unnamed: C26.2, U5.24 (VCOM)
unnamed: C20.2, U5.18 (VDD)
unnamed: C17.2, U5.4 (VGL/NC)
unnamed: C21.2, U5.19 (VPP)
unnamed: C22.2, U5.20 (VSH1)
unnamed: C18.2, U5.5 (VSH2)
unnamed: C24.2, U5.22 (VSL)
unnamed: C30.2, L1.2, U6.4 (AC0)
unnamed: C30.1, L1.1, U6.5 (AC1)

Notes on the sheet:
CONNECTOR PINS
FLASH MEMORY
DEGUGGING SWITCH AND LED
CRYSTAL OSCILLATOR
MICROCONTROLLER
E-Ink
Power
NFC

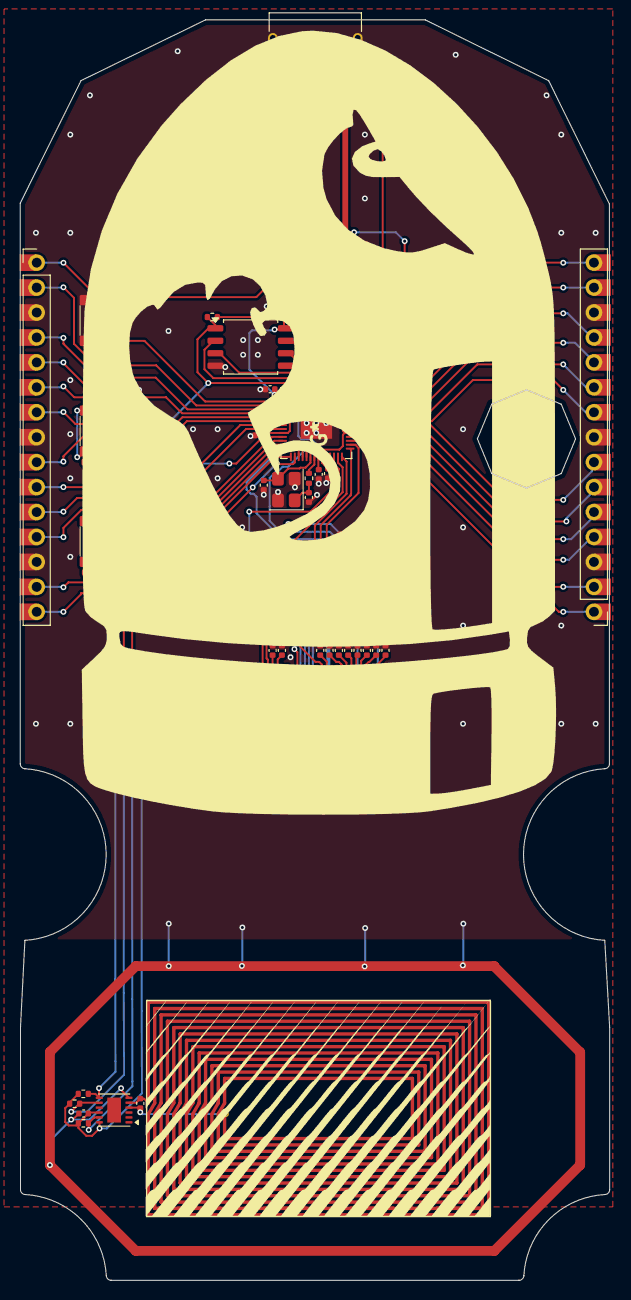
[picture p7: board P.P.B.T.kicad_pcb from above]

Board: 2 copper layers, 60.0 x 128.4 mm, 64 parts (0 on the bottom side), 69 nets.

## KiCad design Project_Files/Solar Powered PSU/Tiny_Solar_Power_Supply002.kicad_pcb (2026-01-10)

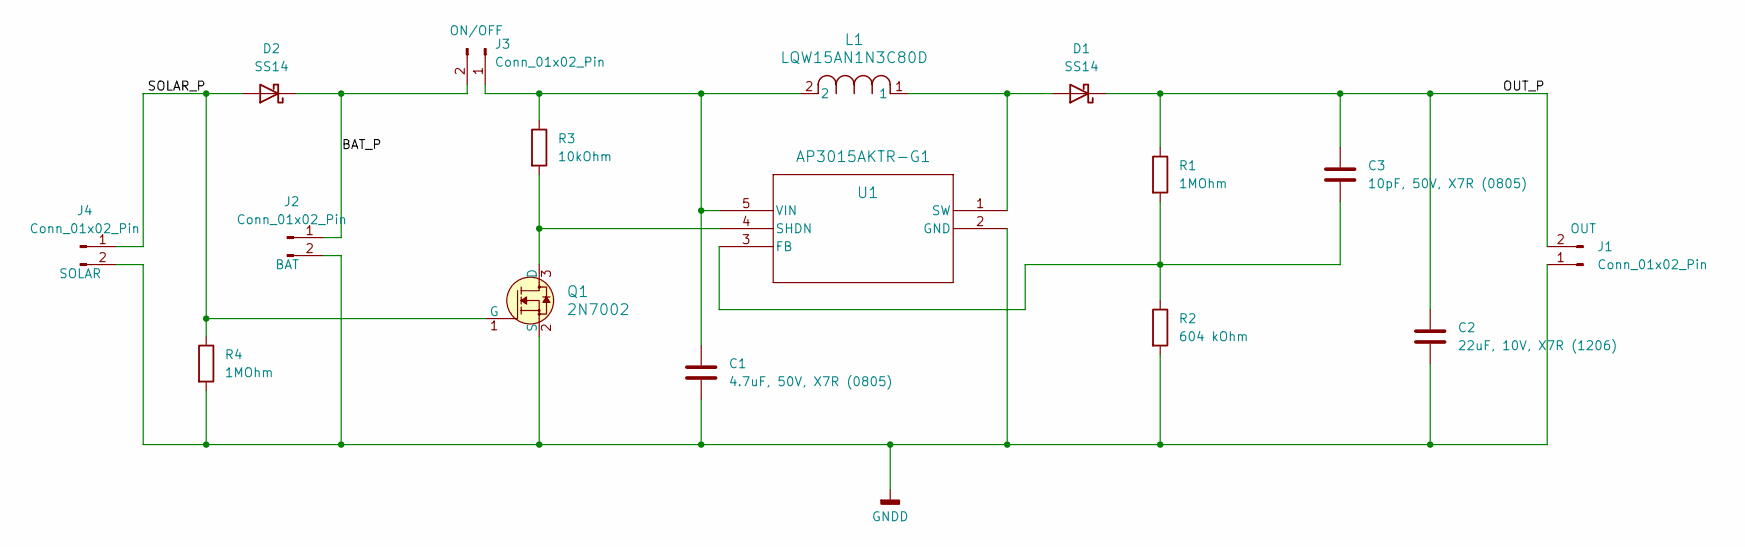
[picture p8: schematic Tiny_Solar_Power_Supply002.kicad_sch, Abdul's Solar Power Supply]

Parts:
C1: 4.7uF, 50V, X7R (0805); C_0805_2012Metric
C2: 22uF, 10V, X7R (1206); C_1206_3216Metric
C3: 10pF, 50V, X7R (0805); C_0805_2012Metric
D1, D2: SS14; D_SMA
J1, J2, J3: Conn_01x02_Pin; PinHeader_1x02_P2.54mm_Vertical
J4: Conn_01x02_Pin; PinHeader_1x02_P2.54mm_Horizontal
L1: LQW15AN1N3C80D; IND_LQW15_MUR
Q1: 2N7002; SOT-23-3; MPN 2N7002; Digi-Key_PN 2N7002NCT-ND
R1, R4: 1MOhm; R_0805_2012Metric
R2: 604 kOhm; R_0805_2012Metric
R3: 10kOhm; R_0805_2012Metric
U1: AP3015AKTR-G1; SOT23-5_1P55X2P9_DIO

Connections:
/BAT_P: D2.1 (K), J2.1, J3.2
/OUT_P: C2.1, C3.1, D1.1 (K), J1.2, R1.1
/SOLAR_P: D2.2 (A), J4.1, Q1.1 (G), R4.1
GNDD: C1.2, C2.2, J1.1, J2.2, J4.2, Q1.2 (S), R2.2, R4.2, U1.2 (GND)
unnamed: D1.2 (A), L1.1, U1.1 (SW)
unnamed: C1.1, J3.1, L1.2, R3.1, U1.5 (VIN)
unnamed: Q1.3 (D), R3.2, U1.4 (SHDN)
unnamed: C3.2, R1.2, R2.1, U1.3 (FB)

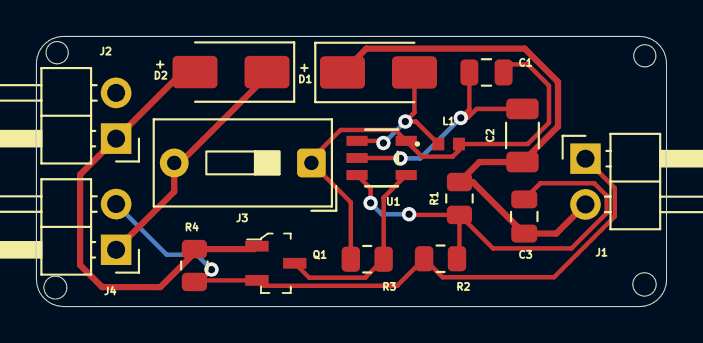
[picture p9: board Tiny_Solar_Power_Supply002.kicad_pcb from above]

Board: 2 copper layers, 35.0 x 15.0 mm, 16 parts (0 on the bottom side), 8 nets.

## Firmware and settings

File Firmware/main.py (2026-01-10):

from machine import Pin, SPI, unique_id
import utime

# ---- SPI SETUP (RP2040) ----
spi = SPI(
    0,
    baudrate=4_000_000,
    polarity=0,
    phase=0,
    sck=Pin(18),
    mosi=Pin(19),
    miso=None
)

# ---- LOAD CONFIG ----
badge_data = {
    "name": None,
    "pronouns": None,
    "slack_handle": None
}

configured = False
try:
    import json
    with open("config.json", "r") as f:
        config = json.load(f)
        badge_data["name"] = config.get("userName")
        badge_data["pronouns"] = config.get("userPronouns")
        badge_data["slack_handle"] = config.get("userHandle")
        configured = True
except Exception as e:
    print("No config file found or error reading it:", e)

# ---- E-INK DRIVER ----
from epd_1in54 import EPD

disp_cs   = Pin(24, Pin.OUT)
disp_dc   = Pin(25, Pin.OUT)
disp_rst  = Pin(26, Pin.OUT)
disp_busy = Pin(27, Pin.IN)

print("Initializing E-Ink display...")
display = EPD(spi, disp_cs, disp_dc, disp_rst, disp_busy)

print("Displaying name on badge...")
display.fill(1)  # white background

name_to_show = badge_data.get("name") or "badge self-test"

display.nice_text(
    name_to_show,
    x=0,
    y=0,
    color=0,
    center=True,
    center_vertical=True
)

display.display()
display.sleep()

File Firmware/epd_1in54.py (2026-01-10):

"""
MicroPython library for Waveshare 1.54" E-Paper Display V2
RP2040 compatible
"""

import framebuf
import utime

EPD_WIDTH  = 200
EPD_HEIGHT = 200

DRIVER_OUTPUT_CONTROL                = 0x01
BOOSTER_SOFT_START_CONTROL           = 0x0C
GATE_SCAN_START_POSITION             = 0x0F
DEEP_SLEEP_MODE                      = 0x10
DATA_ENTRY_MODE_SETTING              = 0x11
SW_RESET                             = 0x12
MASTER_ACTIVATION                    = 0x20
DISPLAY_UPDATE_CONTROL_1             = 0x21
DISPLAY_UPDATE_CONTROL_2             = 0x22
WRITE_RAM                            = 0x24
WRITE_VCOM_REGISTER                  = 0x2C
WRITE_LUT_REGISTER                   = 0x32
SET_DUMMY_LINE_PERIOD                = 0x3A
SET_GATE_TIME                        = 0x3B
BORDER_WAVEFORM_CONTROL              = 0x3C
SET_RAM_X_ADDRESS_START_END_POSITION = 0x44
SET_RAM_Y_ADDRESS_START_END_POSITION = 0x45
SET_RAM_X_ADDRESS_COUNTER            = 0x4E
SET_RAM_Y_ADDRESS_COUNTER            = 0x4F

WF_FULL_1IN54 = bytearray([
    0x80,0x48,0x40,0,0,0,0,0,0,0,0,0,
    0x40,0x48,0x80,0,0,0,0,0,0,0,0,0,
    0x80,0x48,0x40,0,0,0,0,0,0,0,0,0,
    0x40,0x48,0x80,0,0,0,0,0,0,0,0,0,
    *([0x00] * 96),
    0x22,0x22,0x22,0x22,0x22,0x22,0x00,0x00,0x00,
    0x22,0x17,0x41,0x00,0x32,0x20
])

WF_PARTIAL_1IN54_0 = bytearray([
    0x00,0x40,0x00,0,0,0,0,0,0,0,0,0,
    0x80,0x80,0x00,0,0,0,0,0,0,0,0,0,
    0x40,0x40,0x00,0,0,0,0,0,0,0,0,0,
    *([0x00] * 108),
    0x22,0x22,0x22,0x22,0x22,0x22,0x00,0x00,0x00,
    0x02,0x17,0x41,0xB0,0x32,0x28
])

class EPD:
    def __init__(self, spi, cs, dc, rst, busy):
        self.spi = spi
        self.cs = cs
        self.dc = dc
        self.rst = rst
        self.busy = busy

        self.cs.init(self.cs.OUT, value=1)
        self.dc.init(self.dc.OUT, value=0)
        self.rst.init(self.rst.OUT, value=0)
        self.busy.init(self.busy.IN)

        self.buffer = bytearray((EPD_WIDTH // 8) * EPD_HEIGHT)
        self.fb = framebuf.FrameBuffer(
            self.buffer, EPD_WIDTH, EPD_HEIGHT, framebuf.MONO_HLSB
        )

        self.init()

    def send_command(self, c):
        self.dc.value(0)
        self.cs.value(0)
        self.spi.write(bytearray([c]))
        self.cs.value(1)

    def send_data(self, d):
        self.dc.value(1)
        self.cs.value(0)
        self.spi.write(bytearray([d]))
        self.cs.value(1)

    def wait_idle(self):
        while self.busy.value():
            utime.sleep_ms(50)

    def reset(self):
        self.rst.value(1)
        utime.sleep_ms(20)
        self.rst.value(0)
        utime.sleep_ms(5)
        self.rst.value(1)
        utime.sleep_ms(20)

    def init(self):
        self.reset()
        self.send_command(SW_RESET)
        self.wait_idle()

        self.send_command(DRIVER_OUTPUT_CONTROL)
        self.send_data(0xC7)
        self.send_data(0x00)
        self.send_data(0x01)

        self.send_command(DATA_ENTRY_MODE_SETTING)
        self.send_data(0x01)

        self.send_command(SET_RAM_X_ADDRESS_START_END_POSITION)
        self.send_data(0x00)
        self.send_data(0x18)

        self.send_command(SET_RAM_Y_ADDRESS_START_END_POSITION)
        self.send_data(0xC7)
        self.send_data(0x00)
        self.send_data(0x00)
        self.send_data(0x00)

        self.send_command(BORDER_WAVEFORM_CONTROL)
        self.send_data(0x01)

        self.set_lut(WF_FULL_1IN54)

    def set_lut(self, lut):
        self.send_command(WRITE_LUT_REGISTER)
        for i in range(153):
            self.send_data(lut[i])
        self.wait_idle()

    def display(self):
        self.send_command(WRITE_RAM)
        for b in self.buffer:
            self.send_data(b)

        self.send_command(DISPLAY_UPDATE_CONTROL_2)
        self.send_data(0xC7)
        self.send_command(MASTER_ACTIVATION)
        self.wait_idle()

    def clear(self):
        self.fb.fill(1)
        self.display()

    def sleep(self):
        self.send_command(DEEP_SLEEP_MODE)
        self.send_data(0x01)
        self.rst.value(0)

    # Drawing helpers
    def fill(self, c): self.fb.fill(c)
    def text(self, t, x, y, c=0): self.fb.text(t, x, y, c)

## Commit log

2026-01-10 Add files via upload
    BOM AND POSITION FILES
    [Tiny_Solar_Power_Supply002.csv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]
2026-01-10 Create BOM E-paper + NFC.csv
    [BOM E-paper + NFC.csv]
2026-01-10 Update BOM E-paper + NFC.csv
    [BOM E-paper + NFC.csv]
2026-01-10 Rename Solar Panel PSU to Solar Panel PSU.csv
    [Solar Panel PSU.csv]
2026-01-11 Create TOTAL COSTS.csv
    [TOTAL COSTS.csv]
2026-02-03 Update TOTAL COSTS.csv
    [TOTAL COSTS.csv]
